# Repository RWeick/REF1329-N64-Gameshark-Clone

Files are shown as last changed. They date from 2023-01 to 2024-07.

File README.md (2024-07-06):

# REF1329-N64-Gameshark-Pro-Clone
This is a fully functional Nintendo 64 GameShark clone. It implements the original LZ9FC17 GAL on an Altera EPM240, and fully supports all functionality to include: parallel port, 7 segment display, and the GS button.

The LZ9FC17 GAL is the same for both the N64 Gameshark and the N64 Gameshark Pro. All N64 Gameshark and Action Replay firmwares work with this clone.

This is compatible with the Sanni Cartridge Reader's N64 Gameshark programming function as well as the EMS hacked firmware that was released for the first ever Gameshark / Action Replay clone.

The upper EEPROM contains the high bytes of the BIN, and the lower EEPROM contains the low bytes of the BIN. The 2x5 10 pin connector is mapped to the standard Altera USB Blaster pinout for programming. Happy making.

Huge shoutout to @Parasyte for his ceaseless guidance, mentorship, and encouragement, as well as for originally documenting the hardware registers of the N64 Gameshark. This would not exist without him.

Huge shoutout to the [N64Brew](https://n64brew.dev/wiki/Main_Page) community, who have provided countless resources and documentation that enabled me to complete this project.

The Various Gameshark Firmwares directory contains every known firmware in existence. All US firmwares have been collected and preserved there as well as all of the versions I can find from other countries. Please contribute if you have something I do not! It was no small task to collect the U.S. firmwares as some of those are incredibly rare to find today.

[Here's a video of it in action.](https://youtu.be/faCqaDdL_ds)

PCB Thickness: 1.2 mm

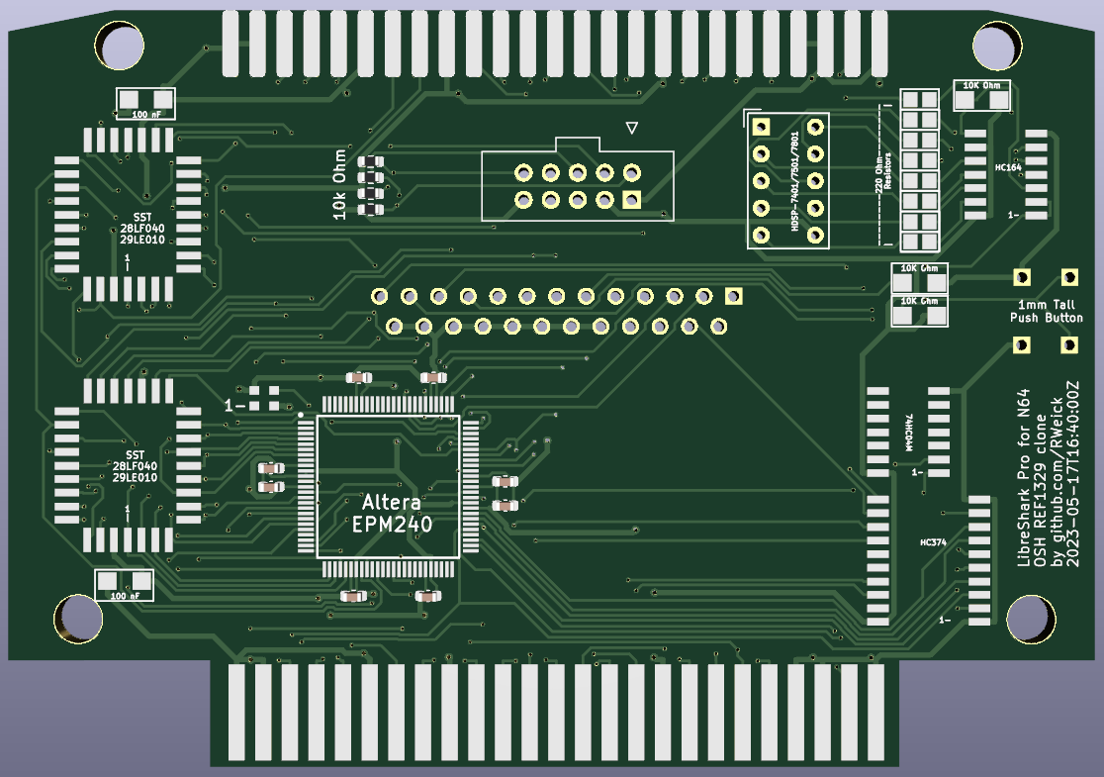
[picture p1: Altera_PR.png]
Front side of the PCB


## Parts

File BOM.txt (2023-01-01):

1x 50 MHz XTAL Oscillator ECS-2033-500-BN

2x SST 29LE010 or 28LF040, PLCC32

1x Altera EPM240T100C5N

2x 100 nF capacitors, SMD, 1206 package size

3x 10k Ohm resistors, SMD, 1206 package size

8x 100 nF capacitors, SMD, 0603 package size

4x 10k Ohm resistors, SMD, 0603 package size

8x 220 Ohm resistors, SMD, 0805 package size

1x HDSP-7401, HDSP-7501, or HDSP-7801

1x DB25, Parallel Port, Male with through-hole pins

1x 6x6x13mm tactile push button

1x HC374A, SOIC-20

1x SN74HC04, SOIC-14

1x SN74HC164, SOIC-14

1x N64 Cartridge slot, 2.5mm or 2.54mm
https://www.aliexpress.us/item/3256803845846403.html?gatewayAdapt=glo2usa4itemAdapt&_randl_shipto=US

1x (2x5 10 pin male connector socket)
https://www.aliexpress.us/item/3256801213832274.html?gatewayAdapt=glo2usa4itemAdapt&_randl_shipto=US

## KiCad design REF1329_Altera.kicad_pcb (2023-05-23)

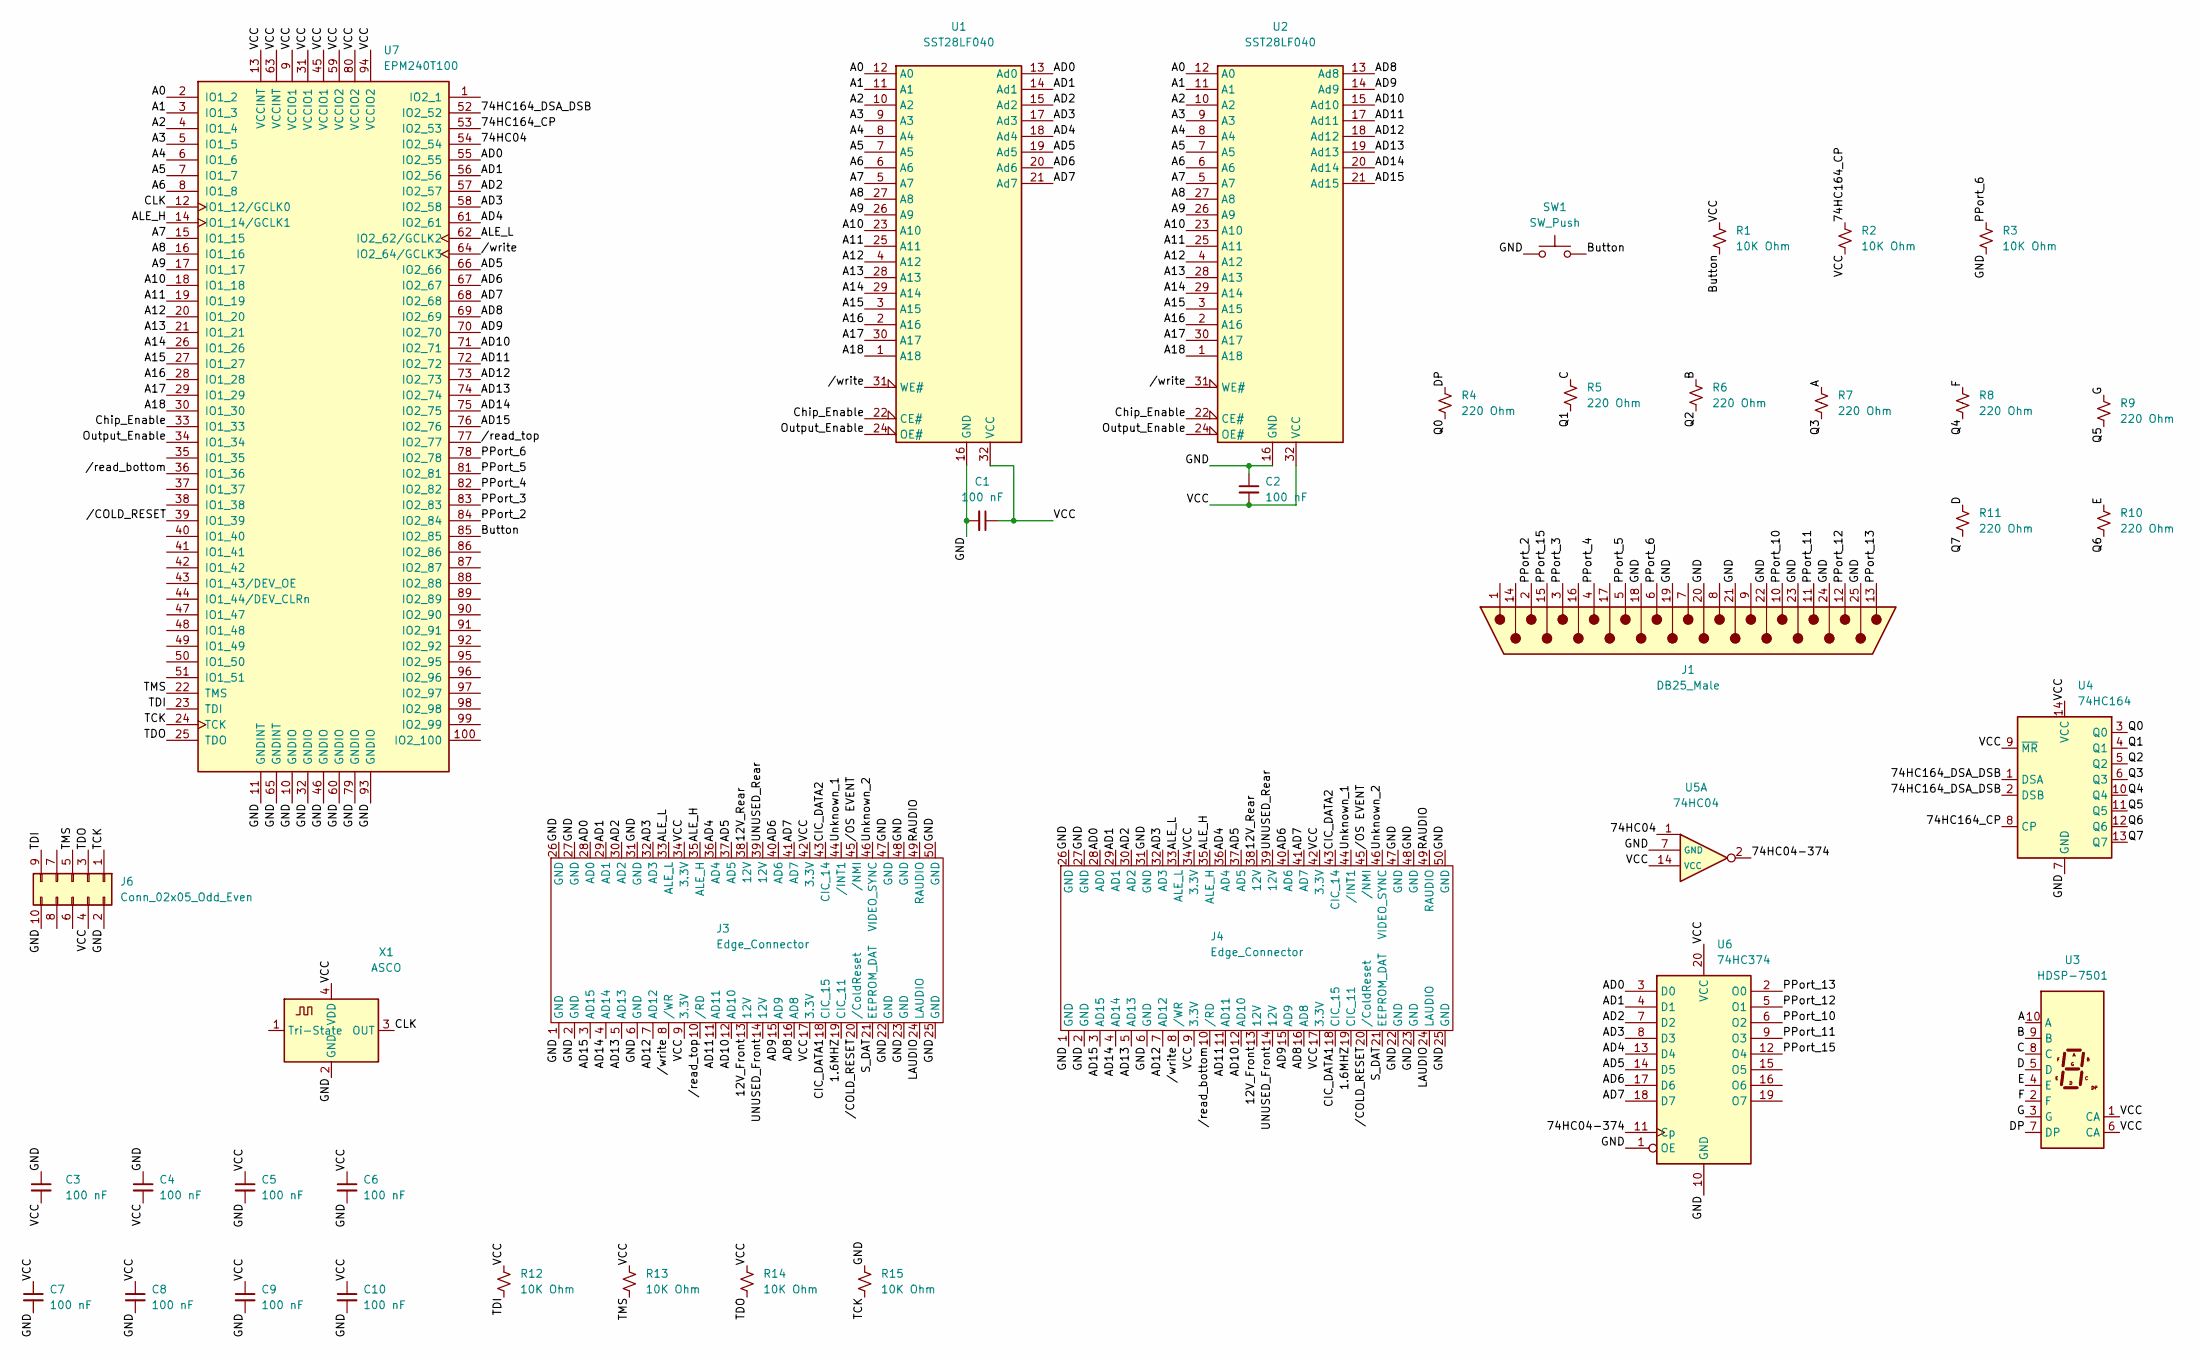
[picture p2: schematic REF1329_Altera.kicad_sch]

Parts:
C1, C2: 100 nF; 100 nF Cap
C3, C4, C5, C6, C7, C8, C9, C10: 100 nF; C_0603_1608Metric
J1: DB25_Male; DSUB-25_Male_Vertical_P2.77x2.84mm
J3: Edge_Connector; Top Edge Connector
J4: Edge_Connector; Bottom Edge Connector
J6: Conn_02x05_Odd_Even; IDC-Header_2x05_P2.54mm_Vertical
R1, R2, R3: 10K Ohm; 10k Ohm Resistor
R4, R5, R6, R7, R8, R9, R10, R11: 220 Ohm; 220 Ohm Resistor
R12, R13, R14, R15: 10K Ohm; R_0603_1608Metric
SW1: SW_Push; 1mm Push Button
U1, U2: SST28LF040; PLCC32
U3: HDSP-7501; HDSP-7401
U4: 74HC164
U5: 74HC04; 74HC04M
U6: 74HC374
U7: EPM240T100; EPM240
X1: ASCO; 50 Mhz Crystal

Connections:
/1.6MHZ: J3.19 (CIC_11), J4.19 (CIC_11)
/12V_Front: J3.13 (12V), J4.13 (12V)
/12V_Rear: J3.38 (12V), J4.38 (12V)
/74HC04: U5.1, U7.54 (IO2_54)
/74HC04-374: U5.2, U6.11 (Cp)
/74HC164_CP: R2.1, U4.8 (CP), U7.53 (IO2_53)
/74HC164_DSA_DSB: U4.1 (DSA), U4.2 (DSB), U7.52 (IO2_52)
/A: R7.1, U3.10 (A)
/A0: U1.12 (A0), U2.12 (A0), U7.2 (IO1_2)
/A1: U1.11 (A1), U2.11 (A1), U7.3 (IO1_3)
/A2: U1.10 (A2), U2.10 (A2), U7.4 (IO1_4)
/A3: U1.9 (A3), U2.9 (A3), U7.5 (IO1_5)
/A4: U1.8 (A4), U2.8 (A4), U7.6 (IO1_6)
/A5: U1.7 (A5), U2.7 (A5), U7.7 (IO1_7)
/A6: U1.6 (A6), U2.6 (A6), U7.8 (IO1_8)
/A7: U1.5 (A7), U2.5 (A7), U7.15 (IO1_15)
/A8: U1.27 (A8), U2.27 (A8), U7.16 (IO1_16)
/A9: U1.26 (A9), U2.26 (A9), U7.17 (IO1_17)
/A10: U1.23 (A10), U2.23 (A10), U7.18 (IO1_18)
/A11: U1.25 (A11), U2.25 (A11), U7.19 (IO1_19)
/A12: U1.4 (A12), U2.4 (A12), U7.20 (IO1_20)
/A13: U1.28 (A13), U2.28 (A13), U7.21 (IO1_21)
/A14: U1.29 (A14), U2.29 (A14), U7.26 (IO1_26)
/A15: U1.3 (A15), U2.3 (A15), U7.27 (IO1_27)
/A16: U1.2 (A16), U2.2 (A16), U7.28 (IO1_28)
/A17: U1.30 (A17), U2.30 (A17), U7.29 (IO1_29)
/A18: U1.1 (A18), U2.1 (A18), U7.30 (IO1_30)
/AD0: J3.28 (AD0), J4.28 (AD0), U1.13 (Ad0), U6.3 (D0), U7.55 (IO2_55)
/AD1: J3.29 (AD1), J4.29 (AD1), U1.14 (Ad1), U6.4 (D1), U7.56 (IO2_56)
/AD2: J3.30 (AD2), J4.30 (AD2), U1.15 (Ad2), U6.7 (D2), U7.57 (IO2_57)
/AD3: J3.32 (AD3), J4.32 (AD3), U1.17 (Ad3), U6.8 (D3), U7.58 (IO2_58)
/AD4: J3.36 (AD4), J4.36 (AD4), U1.18 (Ad4), U6.13 (D4), U7.61 (IO2_61)
/AD5: J3.37 (AD5), J4.37 (AD5), U1.19 (Ad5), U6.14 (D5), U7.66 (IO2_66)
/AD6: J3.40 (AD6), J4.40 (AD6), U1.20 (Ad6), U6.17 (D6), U7.67 (IO2_67)
/AD7: J3.41 (AD7), J4.41 (AD7), U1.21 (Ad7), U6.18 (D7), U7.68 (IO2_68)
/AD8: J3.16 (AD8), J4.16 (AD8), U2.13 (Ad8), U7.69 (IO2_69)
/AD9: J3.15 (AD9), J4.15 (AD9), U2.14 (Ad9), U7.70 (IO2_70)
/AD10: J3.12 (AD10), J4.12 (AD10), U2.15 (Ad10), U7.71 (IO2_71)
/AD11: J3.11 (AD11), J4.11 (AD11), U2.17 (Ad11), U7.72 (IO2_72)
/AD12: J3.7 (AD12), J4.7 (AD12), U2.18 (Ad12), U7.73 (IO2_73)
/AD13: J3.5 (AD13), J4.5 (AD13), U2.19 (Ad13), U7.74 (IO2_74)
/AD14: J3.4 (AD14), J4.4 (AD14), U2.20 (Ad14), U7.75 (IO2_75)
/AD15: J3.3 (AD15), J4.3 (AD15), U2.21 (Ad15), U7.76 (IO2_76)
/ALE_H: J3.35 (ALE_H), J4.35 (ALE_H), U7.14 (IO1_14/GCLK1)
/ALE_L: J3.33 (ALE_L), J4.33 (ALE_L), U7.62 (IO2_62/GCLK2)
/B: R6.1, U3.9 (B)
/Button: R1.1, SW1.2, U7.85 (IO2_85)
/C: R5.1, U3.8 (C)
/CIC_DATA1: J3.18 (CIC_15), J4.18 (CIC_15)
/CIC_DATA2: J3.43 (CIC_14), J4.43 (CIC_14)
/CLK: U7.12 (IO1_12/GCLK0), X1.3 (OUT)
/Chip_Enable: U1.22 (CE#), U2.22 (CE#), U7.33 (IO1_33)
/D: R11.1, U3.5 (D)
/DP: R4.1, U3.7 (DP)
/E: R10.1, U3.4 (E)
/F: R8.1, U3.2 (F)
/G: R9.1, U3.3 (G)
/GND: C1.2, C2.1, C3.1, C4.1, C5.2, C6.2, C7.2, C8.2, C9.2, C10.2, J1.18, J1.19, J1.20, J1.21, J1.22, J1.23, J1.24, J1.25, J3.1 (GND), J3.2 (GND), J3.6 (GND), J3.22 (GND), J3.23 (GND), J3.25 (GND), J3.26 (GND), J3.27 (GND), J3.31 (GND), J3.47 (GND), J3.48 (GND), J3.50 (GND), J4.1 (GND), J4.2 (GND), J4.6 (GND), J4.22 (GND), J4.23 (GND), J4.25 (GND), J4.26 (GND), J4.27 (GND), J4.31 (GND), J4.47 (GND), J4.48 (GND), J4.50 (GND), J6.2, J6.10, R3.2, R15.1, SW1.1, U1.16 (GND), U2.16 (GND), U4.7 (GND), U5.7 (GND), U6.1 (OE), U6.10 (GND), U7.10 (GNDIO), U7.11 (GNDINT), U7.32 (GNDIO), U7.46 (GNDIO), U7.60 (GNDIO), U7.65 (GNDINT), U7.79 (GNDIO), U7.93 (GNDIO), X1.2 (GND)
/LAUDIO: J3.24 (LAUDIO), J4.24 (LAUDIO)
/Output_Enable: U1.24 (OE#), U2.24 (OE#), U7.34 (IO1_34)
/PPort_2: J1.2, U7.84 (IO2_84)
/PPort_3: J1.3, U7.83 (IO2_83)
/PPort_4: J1.4, U7.82 (IO2_82)
/PPort_5: J1.5, U7.81 (IO2_81)
/PPort_6: J1.6, R3.1, U7.78 (IO2_78)
/PPort_10: J1.10, U6.6 (O2)
/PPort_11: J1.11, U6.9 (O3)
/PPort_12: J1.12, U6.5 (O1)
/PPort_13: J1.13, U6.2 (O0)
/PPort_15: J1.15, U6.12 (O4)
/Q0: R4.2, U4.3 (Q0)
/Q1: R5.2, U4.4 (Q1)
/Q2: R6.2, U4.5 (Q2)
/Q3: R7.2, U4.6 (Q3)
/Q4: R8.2, U4.10 (Q4)
/Q5: R9.2, U4.11 (Q5)
/Q6: R10.2, U4.12 (Q6)
/Q7: R11.2, U4.13 (Q7)
/RAUDIO: J3.49 (RAUDIO), J4.49 (RAUDIO)
/S_DAT: J3.21 (EEPROM_DAT), J4.21 (EEPROM_DAT)
/TCK: J6.1, R15.2, U7.24 (TCK)
/TDI: J6.9, R12.2, U7.23 (TDI)
/TDO: J6.3, R14.2, U7.25 (TDO)
/TMS: J6.5, R13.2, U7.22 (TMS)
/UNUSED_Front: J3.14 (12V), J4.14 (12V)
/UNUSED_Rear: J3.39 (12V), J4.39 (12V)
/Unknown_1: J3.44 (/INT1), J4.44 (/INT1)
/Unknown_2: J3.46 (VIDEO_SYNC), J4.46 (VIDEO_SYNC)
/VCC: C1.1, C2.2, C3.2, C4.2, C5.1, C6.1, C7.1, C8.1, C9.1, C10.1, J3.9 (3.3V), J3.17 (3.3V), J3.34 (3.3V), J3.42 (3.3V), J4.9 (3.3V), J4.17 (3.3V), J4.34 (3.3V), J4.42 (3.3V), J6.4, R1.2, R2.2, R12.1, R13.1, R14.1, U1.32 (VCC), U2.32 (VCC), U3.1 (CA), U3.6 (CA), U4.9 (~MR), U4.14 (VCC), U5.14 (VCC), U6.20 (VCC), U7.9 (VCCIO1), U7.13 (VCCINT), U7.31 (VCCIO1), U7.45 (VCCIO1), U7.59 (VCCIO2), U7.63 (VCCINT), U7.80 (VCCIO2), U7.94 (VCCIO2), X1.4 (VDD)
//COLD_RESET: J3.20 (/ColdReset), J4.20 (/ColdReset), U7.39 (IO1_39)
//OS EVENT: J3.45 (/NMI), J4.45 (/NMI)
//read_bottom: J4.10 (/RD), U7.36 (IO1_36)
//read_top: J3.10 (/RD), U7.77 (IO2_77)
//write: J3.8 (/WR), J4.8 (/WR), U1.31 (WE#), U2.31 (WE#), U7.64 (IO2_64/GCLK3)

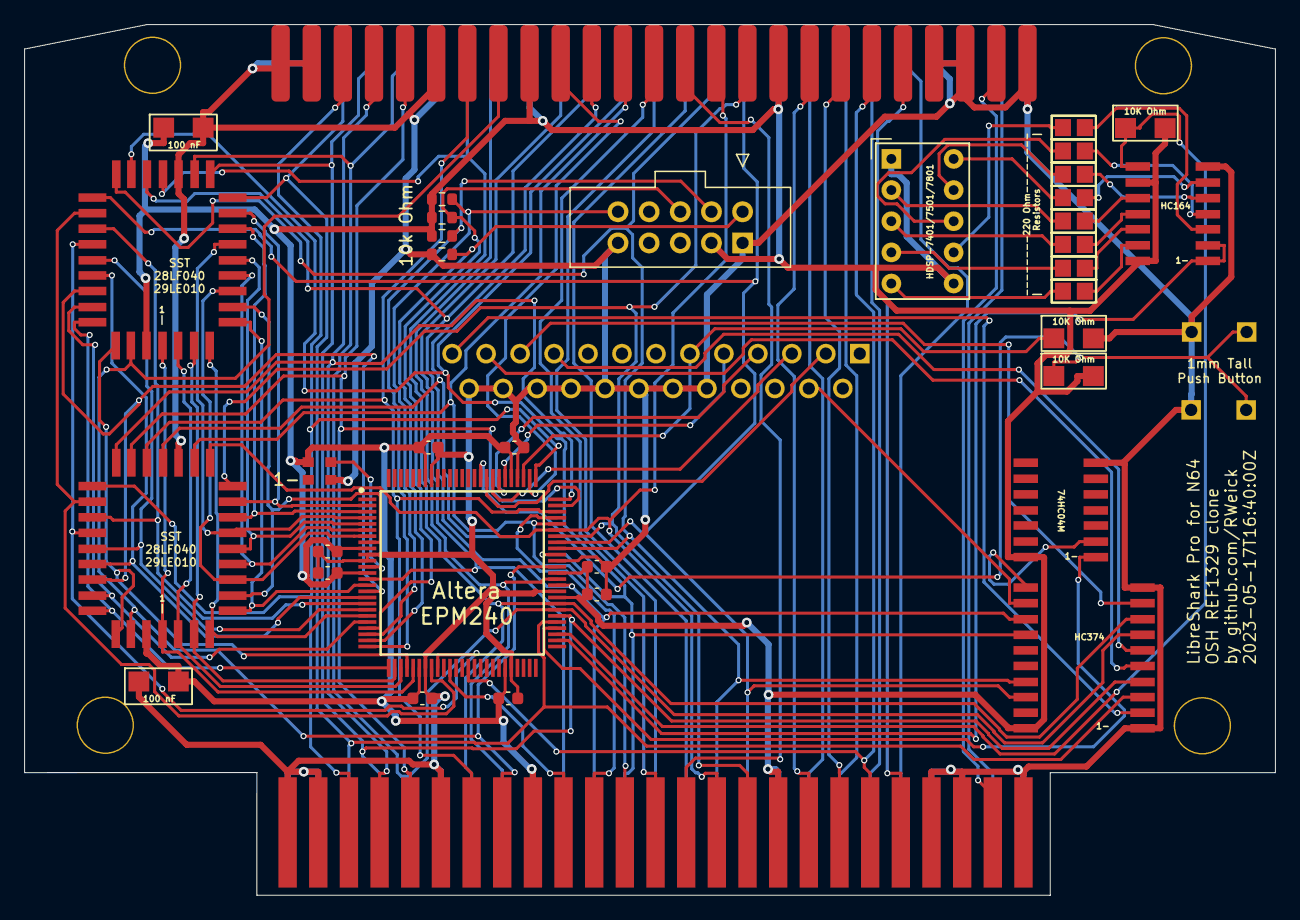
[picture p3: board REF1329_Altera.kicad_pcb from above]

Board: 2 copper layers, 102.0 x 71.0 mm, 42 parts (1 on the bottom side), 94 nets.

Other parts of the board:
Hole1, Hole2, Hole3, Hole4: N64-Hole

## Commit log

2023-05-17 Add .gitignore for local KiCad files
2023-05-17 Add RWeick, LibreShark, and timestamp to PCB silkscreen
    Also make existing silkscreen text larger and avoid overlapping with holes in the board
    [REF1329_Altera.kicad_pcb]
2023-05-17 Relative path to PCB image in README
